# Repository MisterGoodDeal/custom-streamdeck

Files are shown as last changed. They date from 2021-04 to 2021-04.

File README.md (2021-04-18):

# Custom Streamdeck


## The custom Streamdeck is printed in two parts :

 1. The body that can be found in the `Body` folder.
> **Print Settings :** 
> Layer height : 0.2mm
> 
> Infill : 10%
> 
> Nozzle temperature : 200°C (392°F)
> 
> Bed temperature : 60°C (140°F)
> 
> Support : Yes
> 
> Adhesion: No
> 
> Print Speed : 50mm/s (up to 120% speed)
> 
> Initial layer speed : 20mm/s

 2. The front face that can be found une the `Front face` folder.
 > **Print Settings :** 
> Layer height : 0.2mm
> 
> Infill : 10%
> 
> Nozzle temperature : 200°C (392°F)
> 
> Bed temperature : 60°C (140°F)
> 
> Support : Yes
> 
> Adhesion: Yes
> 
> Skirt/Brim speed : 75mm/s 
> 
> Print Speed : 50mm/s
> 
> Initial layer speed : 25mm/s

## Parts
For this project you'll need some hardware :

 - [Arduino Leonardo Pro Micro](https://www.amazon.fr/KeeYees-ATmega32U4-D%C3%A9veloppement-Leonardo-Bootloader/dp/B07FQJW2KN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)
 - [20 CherryMX switches](https://www.amazon.fr/gp/product/B08SK47VDX/ref=ppx_yo_dt_b_asin_title_o03_s00?ie=UTF8&psc=1) (switch type is up to you)
 - A 3D printer obviously, mine is a [Creality Ender 3](https://www.creality3dofficial.com/fr/collections/creality3d-eu-warehouse-in-stock/products/official-creality-ender-3-3d-printer) + [BLTouch](https://www.creality3dofficial.com/fr/collections/creality3d-eu-warehouse-in-stock/products/creality-bl-touch)
 - Some wires
 - Soldering iron + tin solder
 - Heat-shrinkable sleeve

## Electronic diagram & screw dimensions


## Arduino code
The code can be found in the folder `custom_stream_deck_arduino` and you need to install the library `Keypad` that can be found in the folder `custom_stream_deck_arduino\Keypad` that you need to put in the folder `C:\Users\{YOUR_USERNAME}\Documents\Arduino\libraries`

**Update 18/04/2021**
There is a version 2 of the code that can be found in the folder `custom_stream_deck_arduino_v2`. This version allow you to switch between 2 modes : 
1. The mode 1 is emulating key presses from A to T (AZERTY layout) so you can use the custom Streamdeck with [HID Macro](http://www.hidmacros.eu/) for example.
2. The mode 2 is pressing keys from F1 to F10 with LeftCtrl key pushed and LeftShift key if the keycode is odd and LeftAlt if it's not. So you can use it as normal shortcuts

## Custom keycaps
Some custom keycaps can be found in the folder `Custom keycaps`.
The keycaps has been printed with the [Elegoo Mars 2 Pro](https://www.amazon.fr/ELEGOO-Imprimante-Monochrome-dimpression-6-30inch/dp/B08F7M578H), a SLA resin printer

> **Print settings**
> Supports **NEEDED** on the stem key
> 
> The key must be printed on its back
> 
> Resolution : 0.05mm
> 
 *LycheeSlicer file provided with everything already set*

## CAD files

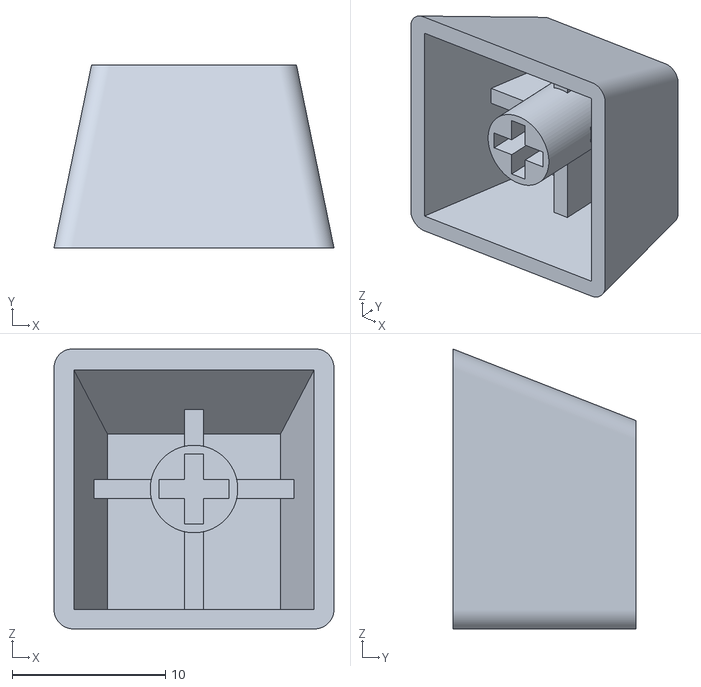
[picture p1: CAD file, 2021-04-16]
Custom keycaps/blankkeycap.STL
18.3 x 11.9 x 18.3

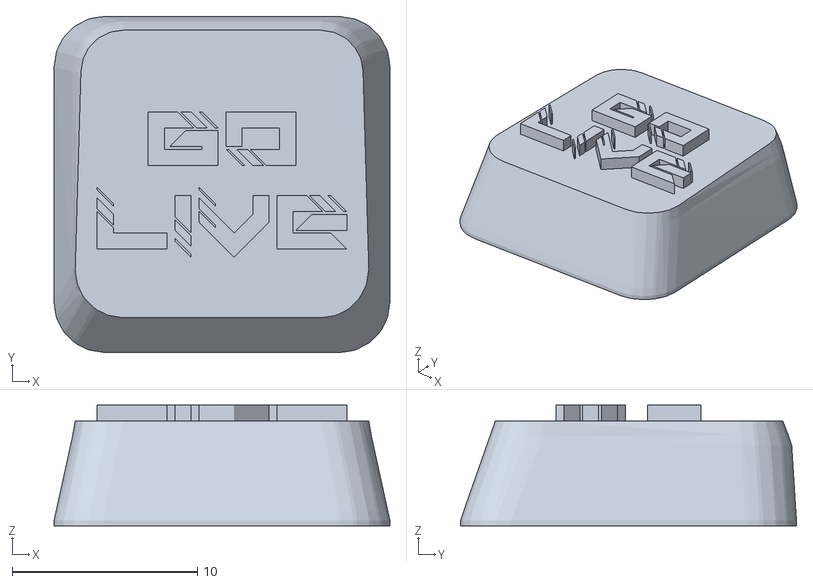
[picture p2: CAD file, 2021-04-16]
Custom keycaps/live/live_keycap.stl
18.1 x 18.1 x 6.50

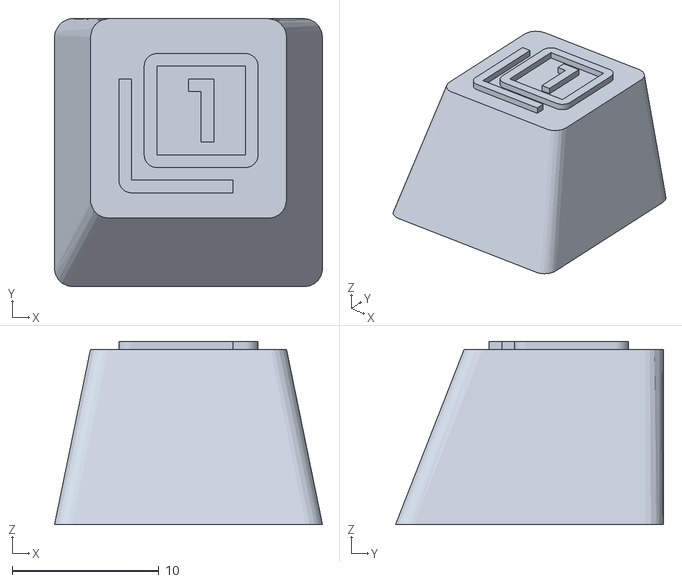
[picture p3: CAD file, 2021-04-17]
Custom keycaps/number/one_alt_v1.stl
18.3 x 18.3 x 12.5

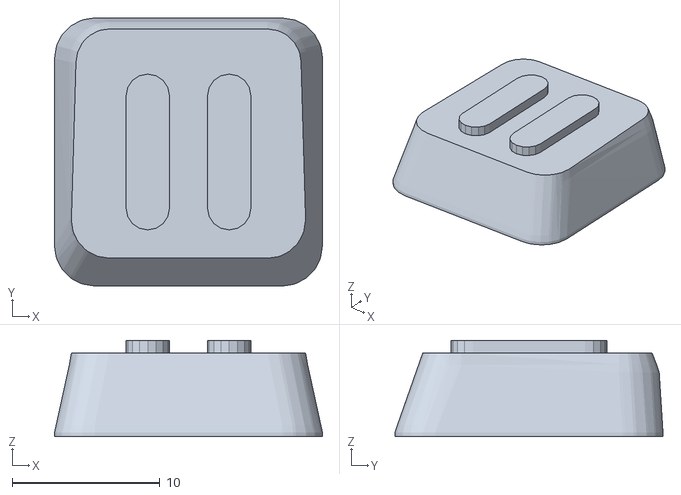
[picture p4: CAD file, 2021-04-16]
Custom keycaps/pause/pause_keycaps.stl
18.1 x 18.1 x 6.50

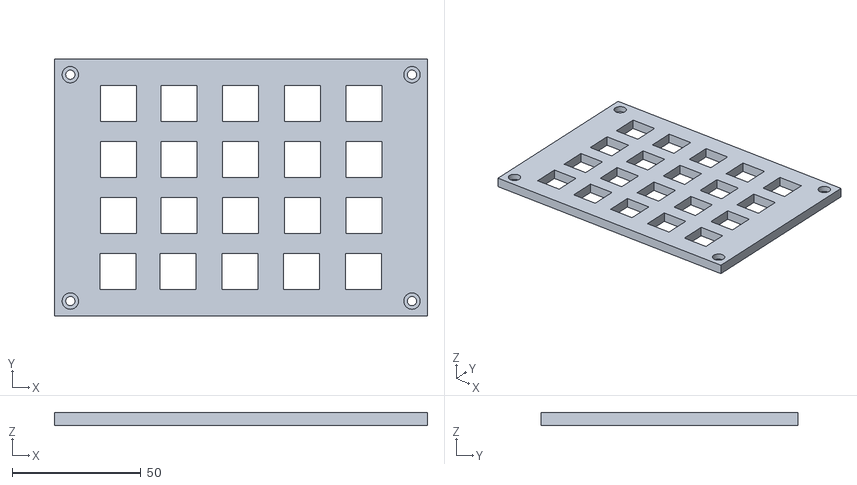
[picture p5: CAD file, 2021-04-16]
Front face/front_face_v1.stl
145.0 x 100.0 x 5.00

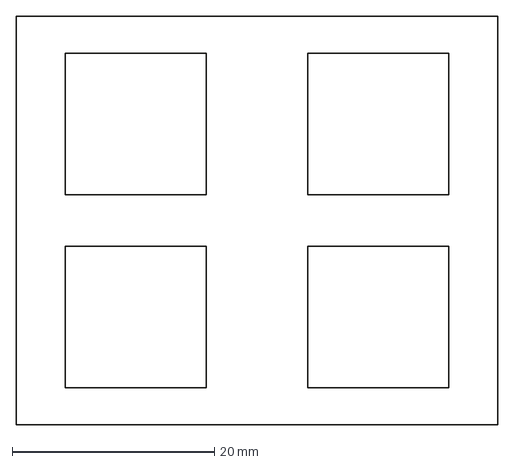
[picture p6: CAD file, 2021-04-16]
Tests/14mm_test.dxf
47.7 x 40.4 mm

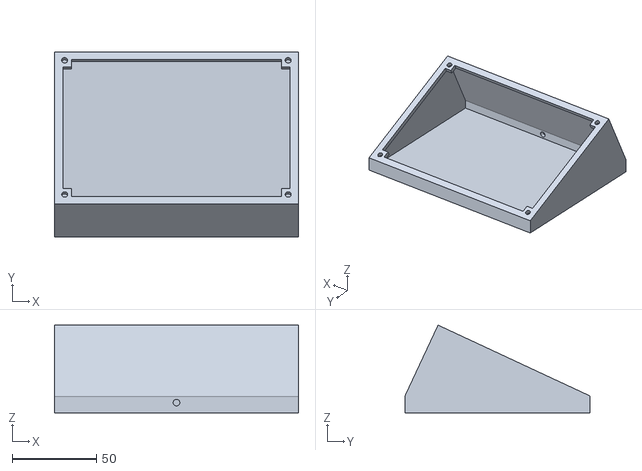
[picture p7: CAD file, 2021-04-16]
Body/body_v1.stl
145.0 x 110.2 x 52.2

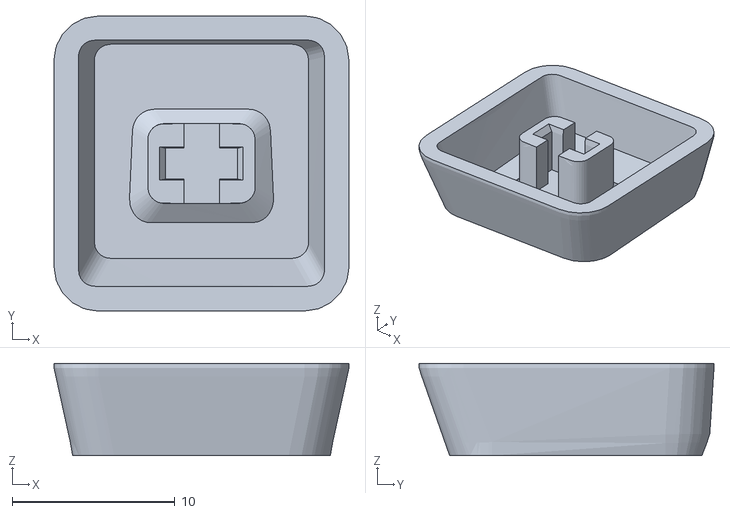
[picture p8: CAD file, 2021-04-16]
Custom keycaps/flatkeycap.stl
18.1 x 18.1 x 5.66

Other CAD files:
Custom keycaps/chat/chat_keycaps_v3.stl
Custom keycaps/game/game_v1.stl
Custom keycaps/obs/obs_keycaps_v3.stl
Custom keycaps/record/record_keycaps_v3.stl
Custom keycaps/reload/reload_v1.stl
Custom keycaps/score/score_v1.stl
Custom keycaps/studio/studio_v1.stl
Custom keycaps/transition/transition_v1.stl
Custom keycaps/live/live_keycap_v3.stl
Custom keycaps/number/two_alt_v1.stl
Body/Body v1.f3d
Body/body_v2.dxf
Body/body_v3.dxf
Custom StreamDeck v1.f3d
Custom keycaps/chat/chat_keycaps.stl
Custom keycaps/chat/chat_keycaps_v2.stl
Custom keycaps/live/live_keycap_v2.stl
Custom keycaps/number/five_alt_v1.stl
Custom keycaps/number/five_v1.stl
Custom keycaps/number/four_alt_v1.stl
Custom keycaps/number/four_v1.stl
Custom keycaps/number/one_v1.stl
Custom keycaps/number/three_alt_v1.stl
Custom keycaps/number/three_v1.stl
Custom keycaps/number/two_v1.stl
Custom keycaps/pause/pause_keycaps_v2.stl
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

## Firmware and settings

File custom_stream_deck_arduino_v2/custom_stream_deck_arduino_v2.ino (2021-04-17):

#include <Keypad.h>
#include <Keyboard.h>

// Keyboard ASCII constants
#define KEY_F1              0xC2
#define KEY_F2              0xC3
#define KEY_F3              0xC4
#define KEY_F4              0xC5
#define KEY_F5              0xC6
#define KEY_F6              0xC7
#define KEY_F7              0xC8
#define KEY_F8              0xC9
#define KEY_F9              0xCA
#define KEY_F10             0xCB
#define KEY_LEFT_CTRL       0x80
#define KEY_LEFT_SHIFT      0x81
#define KEY_LEFT_ALT        0x82

const byte ROWS = 4; // Four rows
const byte COLS = 5; // Five columns

// Custom keys matrix
char hexaKeys[ROWS][COLS] = {
  {'A', 'B', 'C', 'D', 'E'},
  {'F', 'G', 'H', 'I', 'J'},
  {'K', 'L', 'M', 'N', 'O'},
  {'P', 'Q', 'R', 'S', 'T'},
};

byte rowPins[ROWS] = {15, 14, 16, 10}; // Pins numbers for rows
byte colPins[COLS] = {5, 6, 7, 8, 9}; // Pins numbers for columns

boolean isKeyboardFunction = false;

int LED = 2; // Pin for the LED mode
int blinkDelay = 150; // Delay in ms

// Init keypad
Keypad customKeypad = Keypad(makeKeymap(hexaKeys), rowPins, colPins, ROWS, COLS);
String msg;

void setup() {
  Serial.begin(9600);
  customKeypad.setHoldTime(3000);
  customKeypad.addEventListener(keypadEvent);
  pinMode(LED, OUTPUT);
}

void loop() {
  char customKey = customKeypad.getKey();
  if (customKey) {
    if (isKeyboardFunction) {
      switch (customKey) {
        case 'A':
          pressKeys(KEY_LEFT_SHIFT, KEY_F1);
          break;
        case 'B':
          pressKeys(KEY_LEFT_SHIFT, KEY_F2);
          break;
        case 'C':
          pressKeys(KEY_LEFT_SHIFT, KEY_F3);
          break;
        case 'D':
          pressKeys(KEY_LEFT_SHIFT, KEY_F4);
          break;
        case 'E':
          pressKeys(KEY_LEFT_SHIFT, KEY_F5);
          break;
        case 'F':
          pressKeys(KEY_LEFT_SHIFT, KEY_F6);
          break;
        case 'G':
          pressKeys(KEY_LEFT_SHIFT, KEY_F7);
          break;
        case 'H':
          pressKeys(KEY_LEFT_SHIFT, KEY_F8);
          break;
        case 'I':
          pressKeys(KEY_LEFT_SHIFT, KEY_F9);
          break;
        case 'J':
          pressKeys(KEY_LEFT_SHIFT, KEY_F10);
          break;
        case 'K':
          pressKeys(KEY_RIGHT_ALT, KEY_F1);
          break;
        case 'L':
          pressKeys(KEY_RIGHT_ALT, KEY_F2);
          break;
        case 'M':
          pressKeys(KEY_RIGHT_ALT, KEY_F3);
          break;
        case 'N':
          pressKeys(KEY_RIGHT_ALT, KEY_F4);
          break;
        case 'O':
          pressKeys(KEY_RIGHT_ALT, KEY_F5);
          break;
        case 'P':
          pressKeys(KEY_RIGHT_ALT, KEY_F6);
          break;
        case 'Q':
          pressKeys(KEY_RIGHT_ALT, KEY_F7);
          break;
        case 'R':
          pressKeys(KEY_RIGHT_ALT, KEY_F8);
          break;
        case 'S':
          pressKeys(KEY_RIGHT_ALT, KEY_F9);
          break;
        case 'T':
          pressKeys(KEY_RIGHT_ALT, KEY_F10);
          break;
      }
    } else {
      Serial.println(customKey);
      Keyboard.write(tolower(customKey));
    }
  }
  if (isKeyboardFunction) {
    digitalWrite(LED, HIGH);
  } else {
    digitalWrite(LED, LOW);
  }
}

/*
  Function pressKeys : void
  @param key: optionKey => Can be LeftAlt or LeftShift
  @param key: optionKey => Function key that will be pressed

  Description: This function emulate 3 keyboard presses
*/
void pressKeys(byte optionKey, byte functionKey) {
  Keyboard.press(KEY_LEFT_CTRL);
  Keyboard.press(optionKey);
  Keyboard.press(functionKey);
  Keyboard.releaseAll();
}

void keypadEvent(KeypadEvent customKey) {
  switch (customKeypad.getState()) {
    case HOLD:
      if (customKey == 'T') {
        isKeyboardFunction = !isKeyboardFunction;
        Serial.print("SWITCHING_FUNCTION => ");
        Serial.println(isKeyboardFunction);
        blinkLED();
      }
      break;
  }
}

void blinkLED() {
  digitalWrite(LED, HIGH);
  delay(blinkDelay);
  digitalWrite(LED, LOW);
  delay(blinkDelay);
  digitalWrite(LED, HIGH);
  delay(blinkDelay);
  digitalWrite(LED, LOW);
  delay(blinkDelay);
  digitalWrite(LED, HIGH);
  delay(blinkDelay);
  digitalWrite(LED, LOW);
  delay(blinkDelay);
}

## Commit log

2021-04-16 Adding SLA custom keycaps
    [blankkeycap.STL, chat_keycaps.stl, chat_keycaps_v2.stl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]
2021-04-16 Studio keycap
    [studio_v1.stl]
2021-04-16 One keycap
    [two_v1.stl]
2021-04-16 Revert "One keycap"
    This reverts commit a9560c52b8e46c365e0433fbdb99a6cc906ef03d.
    [two_v1.stl]
2021-04-16 Two keycap
    [two_v1.stl]
2021-04-16 Three keycap
    [three_v1.stl]
2021-04-16 Four keycap
    [four_v1.stl]
2021-04-16 Five keycap
    [five_v1.stl]
2021-04-17 Stoopid arduino things
2021-04-17 V2 Scketch
    :heavy_plus_sign: Mode selector => Mode 1 = Using keys from A to T (azerty layout) for using the streamdeck w/ HID Macro for example) ; Mode 2 = Using function key from F1 to F10 with SHIFT, CONTROL 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
    :heavy_plus_sign: Adding LED on pin 2 for mode indicator
2021-04-17 Game keycap
    [game_v1.stl]
2021-04-17 Five alt keycap
    [five_alt_v1.stl]
2021-04-17 Four alt keycap
    [four_alt_v1.stl]
2021-04-17 Three alt keycap
    [three_alt_v1.stl]
2021-04-17 Two alt keycap
    [two_alt_v1.stl]
2021-04-17 One alt keycap
    [one_alt_v1.stl]
2021-04-17 Reload keycap
    [reload_v1.stl]
2021-04-17 Score keycap
    [score_v1.stl]
2021-04-17 Scene transition keycap
    [transition_v1.stl]
2021-04-18 Documenting v2 arduino code
